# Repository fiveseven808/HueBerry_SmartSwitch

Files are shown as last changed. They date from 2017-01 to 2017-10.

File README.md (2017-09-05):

HueBerry: Smart Switch
=============
## IoT Smart Switch for the Philips Hue lighting system

Learn About the hueBerry! (https://youtu.be/YTvbsL82ZcM?t=1m3s "hueBerry is awesome!")

###### Video updated 8/13/2016 *(Outdated)*

## [Discord Channel here!](https://discord.gg/YxUusf8)

## Summary: Updated 2/7/2017
The hueBerry is a dedicated device based on a Raspberry Pi Zero to QUICKLY record and change between Whole house scene! Want to transition your entire home to "bed time" over 30 seconds? now you can! Want in instantaneous "emergency" mode? Now you can do that with ease! It also lets you to control the color temperature and Hue and saturation of individual groups through a quick and friendly interface! No fumbling with a phone or table or PC, just spin and click and spin!
##### Program is currently in open beta

### Features: Updated 9/05/2017

>  * [3D Printable Case!!! Courtsey of Daniel Back](https://www.thingiverse.com/thing:2180872)
>  * Clock! Dims (slightly) during night time (currently hard coded to 9pm)
>  * Control whole Groups and individual Lights!
>  * Control Color temperature and Hue and Saturation of lights OR groups! (for that precise control!)
>  * Assign quick actions to conveniently toggle your lights or set your favorite scene! 
>  * Flashlight mode lol
>  * Create then save whole house scenes with the push of a button! Replay and edit them just as easily!
>  * Adjust the transition time of the whole house scenes between Instant and 30 seconds!

### Technical Features: 

>  * Main menu times out to clock after 30 seconds (customization coming soon)
>  * Automatic Bridge detection and pairing initiation
>  * Scan and Connect to WiFi via WPS!
>  * Settings menu allowing Pi resets, shutdown, and Device and bridge info
>  * One command line install for super easy setup! (beta)
>  * OTA software upgrades!
>  * Unicode support! (beta)
>  * **Undocumented features**
>   * Non WPS WiFi APs added by a text file in the /boot partition
>   * Firmware upgrade possible via placing a special file in the /boot partition
>   * Console and Console Mirroring mode available (for remote debugging/control)

**Requirements:**

  * Optional: [3D Printable Case!!! Courtsey of Daniel Back](https://www.thingiverse.com/thing:2180872)
  * Raspberry Pi (a Zero W is suggested for size reasons)
  * Adafruit_SSD1306 library
  * pigpio library
  * SSD1306 compatible display (128x64 resolution)
  * Rotary encoder with momentary switch
  * Full BOM located [here](https://docs.google.com/spreadsheets/d/18q5wE9IcbJ1D823ktt4ZN7Fp1JHZutR4hCld2env4vI/edit?usp=sharing)

## Instructions as of 2/7/17

  * [Detailed instructions for developers available here!](https://github.com/fiveseven808/HueBerry_SmartSwitch/blob/dev/Dev_setup.md)

**Wishlist:**

  * Gotta clean up repo and get rid of my "training" files
  * More refined menu system programming
    * 2/7 update: Menu code is semi dynamic. Need to make every menu like this. Separate class?
  * Timeout to clock
    * 1/29/17 Needs to be configurable. Affect all menus? (not just main tree)
  * Disable clock via settings
  * Implement Guest mode
    * Guest mode will lock the hueBerry to one group or light allowing for ease of use, without "accidentally" affecting the rest of the house
  * PIR integration?
  * IR remote integration?
    * Push buttons on a universal remote to change scenes!
  * Lower power consumption
    * Move to ESP8266 architecture?
  * Battery state support and icon (low power indicator and graceful shutdown too)
    * Need to design
  * Bugs to squash:
    * Currently need to re-pair with bridge if bridge IP changes...
    * If API key doesn't work on boot, self troubleshoot and see if communication to bridge is bad or API key is bad?
	* Does not complain if bridge does not exist on boot
  * Multiple bridge support (looks like the N-UPnP discovery method supports it)
    * Whole house scenes spanning multiple bridges (for those lucky enough to have that problem lol)
  * This project will be shortly branched into a general toolkit and IoT menu platform for Raspberry Pi Zeros (although all Pis can make use of it)
    * The plan involves creating a custom distribution with all of the required files preloaded so that you can get a pi connected to WiFi with just a screen and a rotary encoder. No HDMI tv or USB widget fussing around necessary!
    * This is particularly useful if you find yourself in a situation where you don't have a computer to get started, but you own a smartphone and have an SSH or VNC app on it!

**License:**

[Creative Commons Attribution-NonCommercial 4.0 International ](https://creativecommons.org/licenses/by-nc/4.0/)  
This is an open source beta program supplied with no guarantee.

**Donations:**

If this project has been useful to you, I'd appreciate it if you would buy me a drink! :D



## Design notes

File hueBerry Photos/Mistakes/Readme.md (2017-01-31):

**Fried Display:**

Not all Chinese 4 pin I2c displays are the same. Their power pins may be switched compared to similar displays. 
The display in this picture underwent reverse voltage for a few seconds... Still works somewhat, but is very very dim. 

**Not like the others:**

Most cheap Wifi adapters (under $3 USD) worked fine with the raspberry pi in my exeperience. However, I ordered 2 
adapters from China that ended up being duds. They would work for a brief amount of time, and then quickly overheat and stop responding. 
In a desktop computer it would last a little longer (half day, then slowly went down to a few minutes, to seconds). Please thoroughly test all 
Wifi adapters before soldering or integrating it into a hueBerry as you may get a dud.

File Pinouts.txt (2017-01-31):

Raspberry pi -> Device
GPIO 16 - D+: Rotary Encoder
GPIO 20 - D-: Rotary Encoder
GND - D GND: Rotary Encoder
GND - Switch GND: Rotary Encoder

GND - GND: I2C SSD1306 128x64 display 
https://learn.adafruit.com/assets/17603
RST - Not connected (Chinese displays don't have this unfortunately)

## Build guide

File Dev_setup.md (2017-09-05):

hueBerry: Setup instructions for Developers
=============
### *"Bare-metal" install instructions for dev-kit*

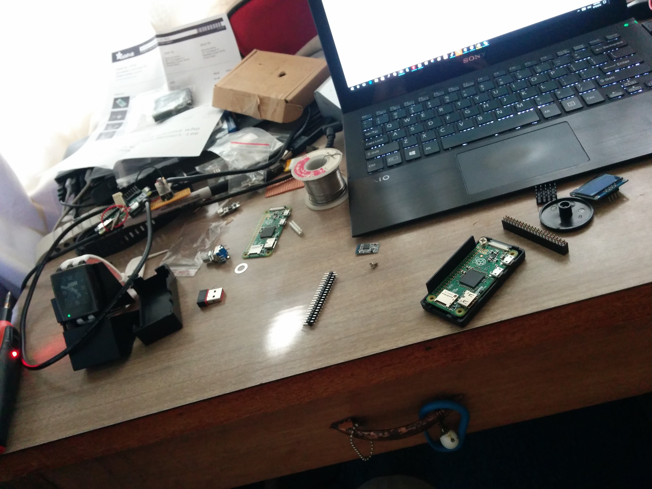
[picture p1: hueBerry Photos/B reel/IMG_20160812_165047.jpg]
hueBerry Mess!


## Getting Started: Updated 1/29/2017
Getting started with the hueBerry from a bare-metal pi is fairly simple. Here, I will attempt to guide you from start to finish!

**Requirements:**
  * Optional: [3D Printable Case!!! Courtsey of Daniel Back](https://www.thingiverse.com/thing:2180872)
  * Raspberry Pi (I used a Zero W)
  * Adafruit_SSD1306 library
  * pigpio library
  * SSD1306 compatible display (128x64 resolution)
  * Rotary encoder with momentary swtich
  * Full BOM located [here](https://docs.google.com/spreadsheets/d/18q5wE9IcbJ1D823ktt4ZN7Fp1JHZutR4hCld2env4vI/edit?usp=sharing)

**Do you meet the dev-kit minimum requirements?** Do you have a display, encoder, pi, and network connection? If so, you may continue! Otherwise, go back and get those components OR you can now run hueBerry in an emulated console session! 

## Bare-Metal Instructions:

* [Install the latest Raspbian distribution](https://www.raspberrypi.org/documentation/installation/installing-images/)
* Wire up the I2C display and rotary encoder (wiring diagrams coming soon)
* [Install the Adafruit_SSD1306 library](https://learn.adafruit.com/ssd1306-oled-displays-with-raspberry-pi-and-beaglebone-black/usage)
```bash
sudo apt-get update
sudo apt-get install build-essential python-dev python-pip
sudo pip install RPi.GPIO
sudo apt-get install python-imaging python-smbus
sudo apt-get install git
git clone https://github.com/adafruit/Adafruit_Python_SSD1306.git
cd Adafruit_Python_SSD1306
sudo python setup.py install
```
* [Install and run pigpiod](http://abyz.co.uk/rpi/pigpio/download.html)
```bash
rm master.zip
sudo rm -rf pigpio-master
wget https://github.com/joan2937/pigpio/archive/master.zip
unzip master.zip
cd pigpio-master
make -j4
sudo make install
sudo pigpiod
```
* You may want to add `sudo pigpiod` to your startup file (I used /etc/rc.local)
* Modify your `/boot/config.txt` file to enable I2c and speed up the bus
```
# Uncomment some or all of these to enable the optional hardware interfaces
dtparam=i2c_arm=on
dtparam=i2c_baudrate=1600000
#dtparam=i2s=on
dtparam=spi=off
```
* *Optional* Disable GUI (to speed up boot?) and lower GPU mem to 8mb
```
gpu_mem=8
start_x=0
```
* *Optional* Overclock your SD card bus to get faster boot speeds
```
dtparam=sd_overclock=100
```
* Clone hueBerry git dev branch then run the main program
```
cd ~
git clone -b dev https://github.com/fiveseven808/HueBerry_SmartSwitch.git
cd HueBerry_SmartSwitch

sudo python hueberry.py
```
* Follow instructions on the screen to pair your hueBerry and bridge
 1. On first run, it should ask you to pair with your Philips hue Bridge.
 1. Follow the onscreen instructions
* Enjoy!
 * *If the above instructions do not work, please contact the maintainer to correct this accordingly*

## OR!
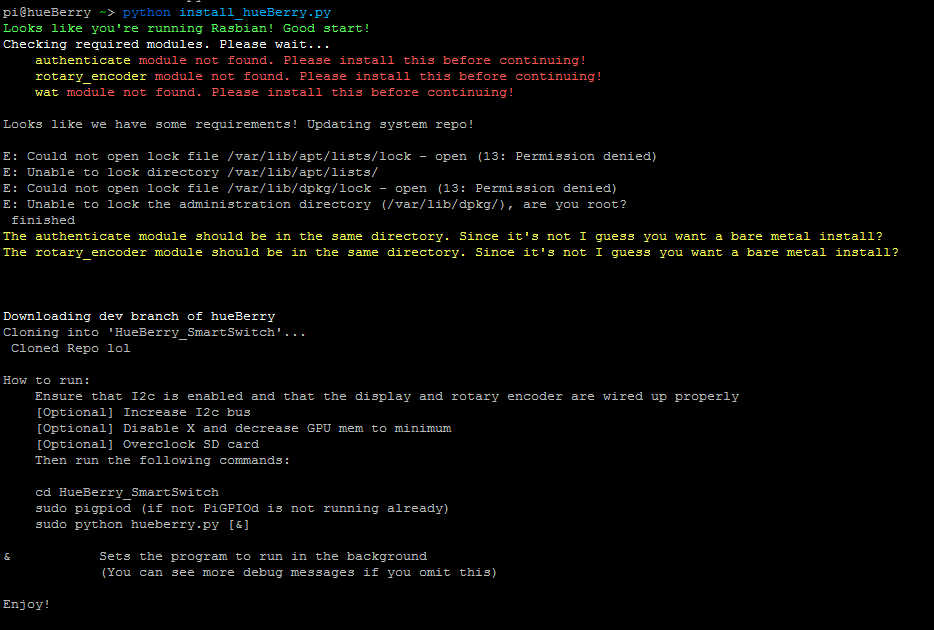
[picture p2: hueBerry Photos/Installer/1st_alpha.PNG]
Installer Beta

If you understand all of the instructions above then a new option is now available for you.
**[Just download the installer](https://github.com/fiveseven808/HueBerry_SmartSwitch/raw/dev/install_hueBerry.py)**
and run `sudo python install_hueBerry.py`. You should understand of the instructions above first is because
this installer is not fully tested and is in a beta state of usability.
But for all tests done so far it works, so I'll leave it here for now.

**License:**

[Creative Commons Attribution-NonCommercial 4.0 International ](https://creativecommons.org/licenses/by-nc/4.0/)  
This is an open source beta program supplied with no guarantee.

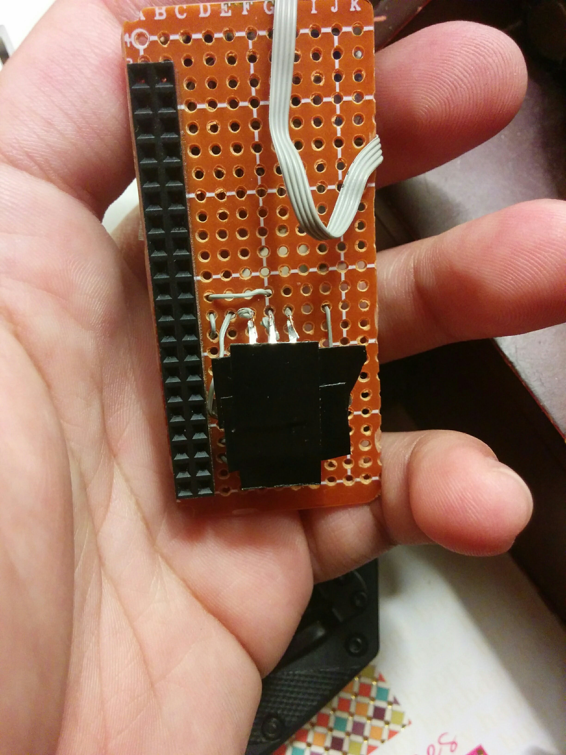
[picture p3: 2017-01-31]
hueBerry Photos/Construction/IMG_20160925_205121.jpg

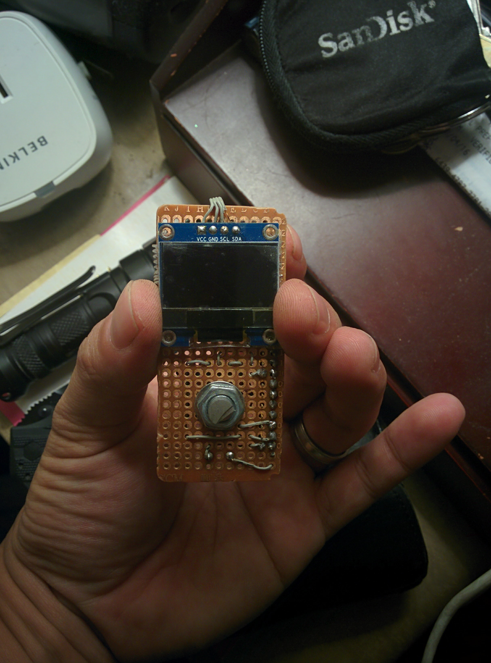
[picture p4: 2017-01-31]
hueBerry Photos/Construction/IMG_20160925_205027.jpg

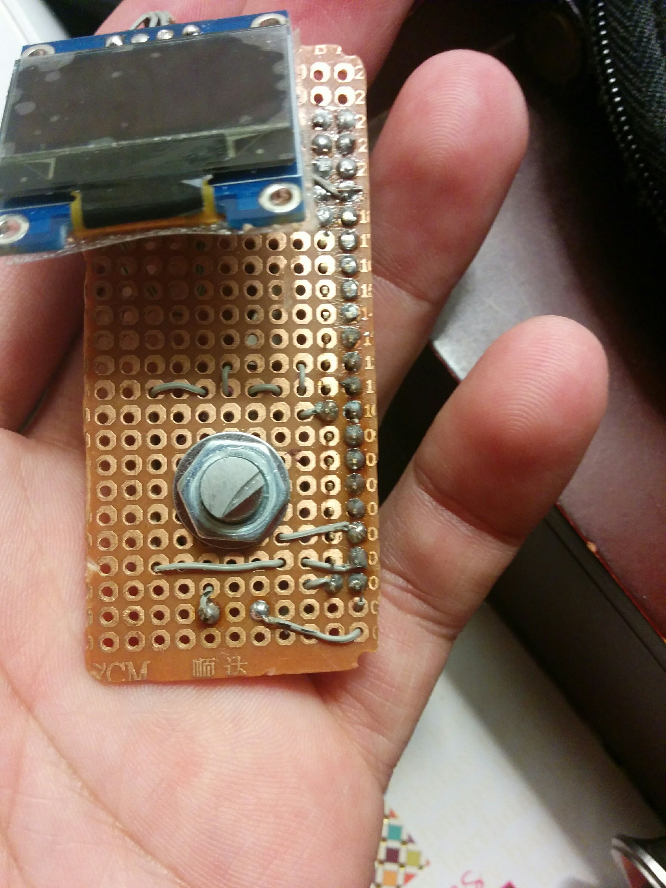
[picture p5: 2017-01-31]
hueBerry Photos/Construction/IMG_20160925_205115.jpg

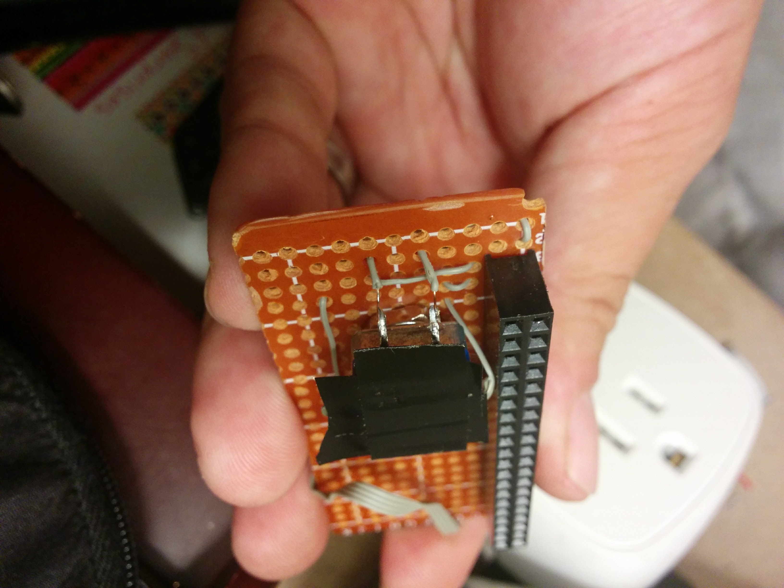
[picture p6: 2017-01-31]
hueBerry Photos/Construction/IMG_20160925_205156.jpg

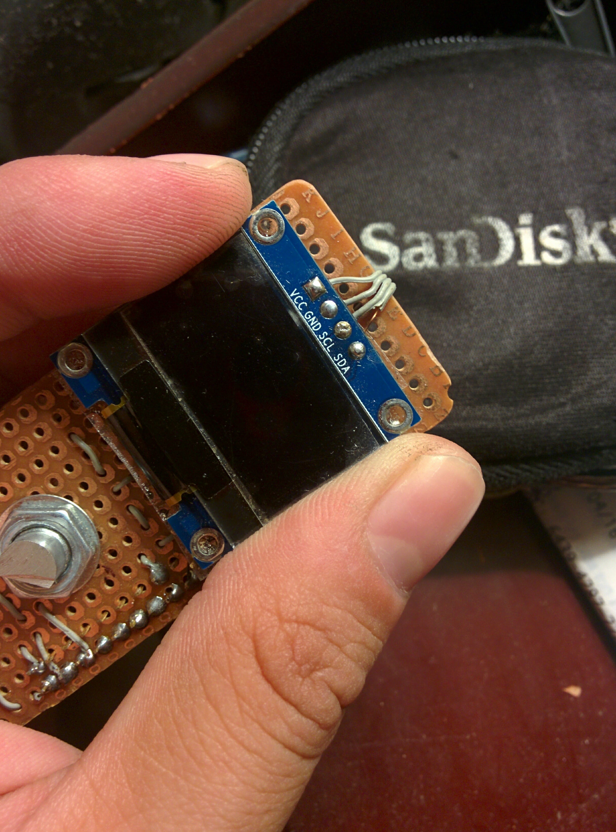
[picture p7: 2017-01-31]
hueBerry Photos/Construction/IMG_20160925_205051.jpg

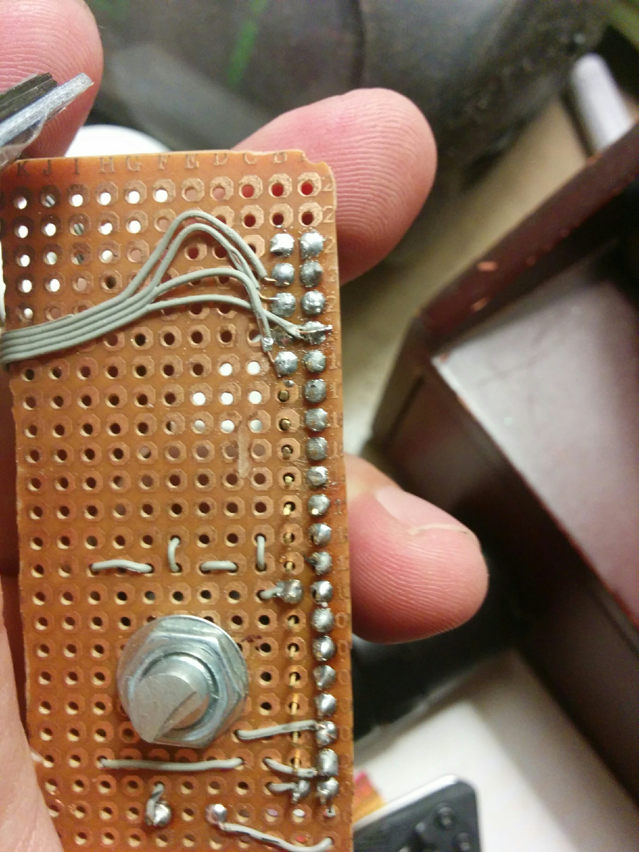
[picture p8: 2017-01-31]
hueBerry Photos/Construction/IMG_20160925_205110.jpg

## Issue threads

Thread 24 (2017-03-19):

Dead/deleted scene in quick actions are not obvious

fiveseven808, 2017-03-19:
Oh man... so lazy... gonna start writing issues in my own repo so i don't forget about bugs i need to squash LOL

If a scene that was assigned to quick actions was deleted, when run by the quick action, all appears normal, however the stdout prints that there is no file.

Remedy:
Somehow interpret the returncode of the process and display a message upon failure. I.e. "%scene% no longer exists"

fiveseven808, 2017-03-22:
fixed!

Closed 2017-03-22.

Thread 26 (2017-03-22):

Weird screen saver actions

fiveseven808, 2017-03-22:
If you push the button (without changing the display) during screensaver mode (screen blank) it runs a thing, but never updates the screen after that lol

Possible solution:
Make it reset the screensaver timer when a button is pushed?
Or make a button push something that wakes up the display? i.e. display 0 and screensaver and button push = timer reset?

fiveseven808, 2017-08-24:
i have no idea what this was for... it doesn't seem like its an isssue? or at least i dont remember what this was for lol

Closed 2017-08-24.

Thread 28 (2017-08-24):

CT not properly saved in Scene Creator

fiveseven808, 2017-08-24:
Not sure what the issue is (maybe a time/lag thing?) but CT does not seem to be saved on the CT only bulbs...

Gotta check on this since it's pretty annoying...

darakian, 2017-10-09:
What is CT?

fiveseven808, 2018-01-17:
Color Temperature. It's an attribute received in the JSON packet for a given light that supports it.

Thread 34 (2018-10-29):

Menu timeout not working

fiveseven808, 2018-10-29:
Haven't had time to address this...

Looks like the menu timeout isn't working properly in the current version

steps to reproduce:
change to a 1st level menu item that isn't clock
wait for timeout, no timeout happens... screen stays lit

however the internal menu counter seems to have reset to zero..

this will contribute to more burn in and is quite annoying

[additional] need to add the menu timeout to all levels of menu... should be a bit easier with the new menu code.

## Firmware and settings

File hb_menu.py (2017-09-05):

import hb_encoder
import hb_display
import time

class Menu_Creator(object):
    def __init__(self, menu_layout, debug = 0, mirror_mode = 0, rotate = 0, spi_display = 0):
        debug_argument = debug
        self.offset = 0 #carryover
        self.post_offset = 0 #carryover
        self.menu_layout = menu_layout
        self.exitvar = 0
        # Create Display Object
        # Maybe instead of create? get passed display object from hueberry? would make this less independent though... and confusing...
        if(mirror_mode == 1):
            self.hb_display = hb_display.display(console = 1,mirror = mirror_mode)
        else:
            self.hb_display = hb_display.display(console = debug_argument,mirror = mirror_mode, rotation = rotate, spi_display = spi_display)
        # Create Encoder Object
        if (debug_argument == 0):
            self.encoder = hb_encoder.RotaryClass()
        elif (debug_argument == 1):
            self.encoder = hb_encoder.RotaryClass(debug = 1)

    def run_simple_menu(self):
        """
        menu_layout = ("1st menu",lambda: printmenu("oshit! it works!"),
                    "2nd menu",lambda: printmenu("doing a second thing"),
                    "quit",lambda: sys.exit())
        """
        timeout = 0
        displaytemp = 0
        prev_secs = 0
        old_display = 0
        refresh = 1
        pushed = 0
        menu_timeout = 30
        depth_divisor = 2 # how many menu items per line. i.e. 1 title + 1 function = 2
        self.encoder.wait_for_button_release()
        while True:
            total_screens = len(self.menu_layout)
            total_plus_offset = total_screens + self.offset
            menudepth = (total_plus_offset + self.post_offset - depth_divisor)/depth_divisor
            # Cycle through different displays
            if(self.encoder.pos > menudepth):
                self.encoder.pos = menudepth
            elif(self.encoder.pos < 0):
                self.encoder.pos = 0
            display = self.encoder.pos*2 # because pos is a pre/bounded variable, and encoder.pos has been forced down.
            display_number = (display/2)+1
            #Display Selected Menu
            if (old_display != display or refresh == 1):
                if(display >= self.offset and display <= (total_plus_offset-1)):
                    self.hb_display.display_2lines(str(display_number) + ". " + str(self.menu_layout[display-self.offset]),"Run?",15)
                refresh = 0
                old_display = display
            time.sleep(0.005)
            secs = int(round(time.time()))
            timeout_secs = secs - prev_secs
            if(display != 0 and displaytemp != display):
                prev_secs = secs
                displaytemp = display
            elif(display != 0 and timeout_secs >= menu_timeout):
                self.encoder.pos = 0
                display_temp = 0
            elif(display == 0):
                displaytemp = display
            pos,pushed = self.encoder.get_state() # after loading everything, get state#
            if (pushed):
                if(display >= self.offset and display < total_plus_offset):
                    #print display
                    if self.menu_layout[display+(depth_divisor-1)] == "exit":
                        #print "exiting"
                        #time.sleep(2)
                        break
                    self.menu_layout[display+(depth_divisor-1)]()
                time.sleep(0.01)
                #prev_millis = int(round(time.time() * 1000))
                self.encoder.pos = 0
                refresh = 1
            #time.sleep(0.1)

    def run_2_line_menu(self):
        """
        menu_layout = ("Name 1", "Name 2", lambda: do_thing_1(),
                        "Name 3", "Name 4", lambda: do_thing_2(),
                        "Back to", "Main Menu", "exit")
        """
        timeout = 0
        displaytemp = 0
        prev_secs = 0
        old_display = 0
        refresh = 1
        pushed = 0
        menu_timeout = 30
        depth_divisor = 3 # how many menu items per line. i.e. 1 title + 1 function = 2
        return_status = 0
        self.encoder.wait_for_button_release()
        while True:
            total_screens = len(self.menu_layout)
            total_plus_offset = total_screens + self.offset
            menudepth = (total_plus_offset + self.post_offset - depth_divisor)/depth_divisor
            # Cycle through different displays
            if(self.encoder.pos > menudepth):
                self.encoder.pos = menudepth
            elif(self.encoder.pos < 0):
                self.encoder.pos = 0
            display = self.encoder.pos*3 # because pos is a pre/bounded variable, and encoder.pos has been forced down.
            display_number = (display/3)+1
            #Display Selected Menu
            if (old_display != display or refresh == 1):
                if(display >= self.offset and display <= (total_plus_offset-1)):
                    if callable(self.menu_layout[display-self.offset]) == False:
                        self.hb_display.display_2lines(str(display_number) + ". "+str(self.menu_layout[display-self.offset]),str(self.menu_layout[display-self.offset+1]),17)
                    else:
                        self.menu_layout[display-self.offset]()
                refresh = 0
                old_display = display
            #elif(display != 0):
            #    time.sleep(0.005)
            time.sleep(0.005)

            secs = int(round(time.time()))
            timeout_secs = secs - prev_secs
            if(display != 0 and displaytemp != display):
                prev_secs = secs
                displaytemp = display
            elif(display != 0 and timeout_secs >= menu_timeout):
                self.encoder.pos = 0
                display_temp = 0
            elif(display == 0):
                displaytemp = display
            #if(display != 0):
            #    print timeout_secs

            # Poll button press and trigger action based on current display
            #if(not GPIO.input(21)):
            #print self.exitvar
            pos,pushed = self.encoder.get_state() # after loading everything, get state#
            if (pushed):
                if(display >= self.offset and display < total_plus_offset):
                    #print display
                    if self.menu_layout[display+(depth_divisor-1)] == "exit":
                        # If a menu item has "exit" as the function/action thing, then exit
                        return 0
                    # Position [1] or [2] can be interpeted as type (all caps)
                    if self.menu_layout[1] == "BD_TYPE" or self.menu_layout[2] == "BD_TYPE":
                        # If BD_TYPE menu
                        if display != 0 :
                            return self.menu_layout[display+(depth_divisor-1)]()
                        if display == 0:
                            # Make sure to do nothing when the "Question" for BD_TYPE is selected
                            pass
                    else: # If normal type menu
                        # This is where the object that's selected actually runs...
                        return_status = self.menu_layout[display+(depth_divisor-1)]()
                    if return_status == "BREAK_MENU":
                        return
                time.sleep(0.01)
                refresh = 1
                #prev_millis = int(round(time.time() * 1000))
                self.encoder.pos = display/depth_divisor #resume where you came from
            #time.sleep(0.1)
        return

    def single_value_menu(self, main_title,value_title,
                                calc_func, rev_calc,
                                action_func,
                                start_pos,a_param,
                                min_val, max_val,
                                timeout, timeout_func):
        #Need to detmermine initial encoder position
        self.encoder.pos = int(start_pos)
        max_rot_val = max_val
        bri_pre = calc_func(self.encoder.pos)
        refresh = 1
        prev_mills = 0
        self.encoder.wait_for_button_release()
        pos = self.encoder.pos
        while True:
            if(self.encoder.pos > max_rot_val):
                self.encoder.pos = max_rot_val
            elif(self.encoder.pos < min_val):
                self.encoder.pos = min_val
            mills = int(round(time.time() * 1000))
            millsdiff = mills - prev_mills
            rot_bri = calc_func(self.encoder.pos)
            if(bri_pre != rot_bri or refresh ==  1 ):
                self.hb_display.display_2lines(main_title,value_title + str(int(rot_bri)) + "%",17)
                refresh = 0
            if rot_bri <= min_val and rot_bri != bri_pre:
                print"turning off since below min value"
                #hue_groups(lnum = group,lon = "false",lbri = rot_bri,lsat = "-1",lx = "-1",ly = "-1",ltt = "5", lct = "-1")
                #huecmd = threading.Thread(target = hue_groups, kwargs={'lnum':group,'lon':"false",'lbri':int(rot_bri),'lsat':"-1",'lx':"-1",'ly':"-1",'ltt':"5",'lct':"-1"})
                #huecmd.start()
                bri_pre = rot_bri
            elif(rot_bri != bri_pre and millsdiff > 200):
                print"millsdiff > 200"
                print"running actionfunc with rot_bri calcuated result"
                action_func(pos)
                #hue_groups(lnum = group,lon = "true",lbri = rot_bri,lsat = "-1",lx = "-1",ly = "-1",ltt = "5", lct = "-1")
                #huecmd = threading.Thread(target = hue_groups, kwargs={'lnum':group,'lon':"true",'lbri':int(rot_bri),'lsat':"-1",'lx':"-1",'ly':"-1",'ltt':"5",'lct':"-1"})
                #huecmd.start()
                bri_pre = rot_bri
                prev_mills = mills
            millsdiff = mills - prev_mills
            if(millsdiff > timeout):
                #If 5.0 seconds have passed and nothing has happened, go and refresh the display and reset the miliseconds
                #rot_bri,wholejson = get_huejson_value("g",group,"bri")
                self.hb_display.display_2lines(main_title,value_title + str(int(rot_bri)) + "%",17)
                timeout_func(pos)
                print "the rot bri after 5 sec is: "+str(rot_bri)
                prev_mills = mills
            pos,pushed = self.encoder.get_state()
            if(pushed):
                return #exit function goes here
            time.sleep(0.01)
            refresh = 1


def printmenu(text):
    print(text)
    time.sleep(1)

# For testing
if __name__ == "__main__":
    import hb_menu
    import sys
    tm_menu = ("1st menu",lambda: printmenu("oshit! it works!"),
                "2nd menu",lambda: printmenu("doing a second thing"),
                "3rd menu",lambda: printmenu("doing a third thing"),
                "quit",lambda: sys.exit())
    testmenu = hb_menu.Menu_Creator(debug = 1,menu_layout = tm_menu)
    testmenu.run_simple_menu()

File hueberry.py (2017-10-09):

#!/usr/bin/env python
__version__ = "v051-0905.57.a"
"""
2017-09-05 //57
* I really want to update the master branch... So this is some simple modifications to undo the dev features
- Scene upgrader removed and placeholder in place right now
+ Added WPBack's 3d printable model of the hueBerry case!!!
+ Want to push to master!

2017-07-24 //57
* Have not touched this code in 3 months it seems... I don't remember how this
    works lol. Will attempt to add scene updater tool...
* Scene updater tool will work as follows:
    * User replaces lights in system.
    * Navigate to and run Scene Updater
    * Selects how many lights to replace (and option to cancel)
    * Select 1st light to replace (and option to go back or cancel)
    * Select 1st light to replace with (and option to go back or cancel)
    * Select n light to replace (and option to go back or cancel)
    * Select n light to replace with (and option to go back or cancel)
    * Dict? List? Array? Will be created like {(lights:1, 15),(lights:2, 16),(lights:10, 17)}
    * Menu title: Lights to be replaced
        * Mappings will be displayed in a scrollable style (and option to cancel)
        * Future features:
            * Detect if a mapping error has occured (multiple lights mapped to same light, etc)
            * Click to edit individual Mappings
        * Submit button
        * Binary decision menu to confirm that it will affect all scenes
    * Will parse/grep/replace the "*lights/1*" string with the "*lights/15*"
        string in all files in the scenes directory

2017-04-30 //57
+ Fixed a bug preventing scenes from being created

2017-04-07 //57
* Mega Alpha version
* Forgot to add release notes LOL
+ Intelligent Display handling (kind of)
+ Check I2C display, if not, then SPI, if not then morse code IP address via onboard LED!
+ Rotate display is a thing now (not tested well)
+ Dynamic menu struture implemented
+ Enforced running as root
+ Created a non-root mode
+ Added a demo mode (super alpha)


--------
Things to do
Short term goals:
*
Long term goals:
* Handle adding Wifi without screen? (try except displaying on a screen?)
* If no screen is detected, signal via the onboard led that wifi adding is complete?
* Dynamic (or seperate) Menu for Util mode? (Clock, Util Settings menu, chck for programs not scenes)



--------------------
http://www.diveintopython.net/scripts_and_streams/command_line_arguments.html
this is probably a good reference on how to program this in the future
--------------------
bug:
--------------------
philips hue bug
need to repair when no bridge found

search and test auth?
ping on startup?

check for response?
nothing found?
"""

def print_usage():
    usage = """
    How to run:
        sudo python hueberry.py [-d] [-m] [-s] [-nb] [-wsl] [-util] [-r180] [-spi] [-h,--help]

    -d              Sets the program to output and take input from the console

    -m              Turns on mirror mode. Outputs to the
                    display as well as the terminal.

    -s,--simulate   Set the updater to simulate mode ( no changes made )

    -nb             No Bridge mode. Run this if debugging with no bridge

    -wsl            Disables weird logging (quick fix for Windows Subsystem for Linux)

    -util           Turns on HB-Utility mode. No hue related options avaliable.
                    Faster boot time too

    -r180           Flip the display 180 degrees

    -spi            Run hueBerry with a SPI driven SSD1306 display vs I2C

    -nr, --noroot   Allows hueBerry to run as a normal user with REDUCED functionality
                    The following features WILL NOT WORK and may crash the program:
                    OTA Updater, Add wifi via txt file, Update via file on sd card,
                    View IP (possibly), Connect to Wifi, Exit to terminal

    -h,--help       Displays this help text

    ex: python hueberry.py -d -nb -wsl -nr
    This will allow hueberry to run in WSL without the hue system or root
    """
    print(usage)

import os, logging
#set working directory to script directory
os.chdir(os.path.dirname(os.path.abspath(__file__)))

import sys
#Defaults
debug_argument = 0
mirror_mode = 0
bridge_present = 1
wsl_env = 0
simulation_arg = 0
rotate = 0
curses_test = 0
util_mode = 0
spi_display = 0
rootless = 0
for arg in sys.argv:
    if arg == '-d':
        debug_argument = 1
    if arg == '-m':
        mirror_mode = 1
    if arg == "-nb":
        bridge_present = 0
    if arg == '-wsl':
        wsl_env = 1
    if arg == '-util':
        wsl_env = 1
        bridge_present = 0
        util_mode = 1
    if arg == '-r180':
        rotate = 180
    if arg == '-curses':
        curses_test = 1
    if arg in ("-s","--simulate"):
        simulation_arg = 1
    if arg in ("-spi"):
        spi_display = 1
    if arg in ("-nr","--noroot"):
        rootless = 1
    if arg in ("-h","--help"):
        print_usage()
        sys.exit()

if debug_argument != 1:
    os.popen("python splashscreen.py &")

import threading
import time

import authenticate

import json
import colorsys
import math
import pprint
import hb_display
import hb_encoder
import hb_hue
import hb_settings
import hb_menu
import curses

print "Finished Importing all modules! hopefully this will work!"

# For when I want to measure the time of all of the modules loading
# Using the dot graph method Described here:
# http://stackoverflow.com/questions/767881/time-taken-by-an-import-in-python
#sys.exit()
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

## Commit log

2016-08-12 v008 update
    v008 update
    uses the functions built in 007 and now automatically
    retrieves group and light names from the hub
    now when using the group or
    light modifier, you'll know exactly what you're controlling
    and in case
    you have dead light spots (i.e. removed from system) then it'll skip
    over that as well.
    deleted a couple of functions that aren't being
    used anymore.
    also added to the brightness change function to get the
    state of the light before hand and update it
    changed representation
    from 0-250 to 0-100%
    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
    [v005.py, v006.py, v007.py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]
2016-08-14 authenticate module
    This module is set up so you don't need to hardcode any info. you can create a "auth" option on the device that will run through the necessary steps to auth. see authtest.py for a crude example
2016-08-15 fixed issue
    didn't test the lights as i should've... wasn't working. fixed the issue
    with a space LOL. the new url string wasn't seperated properly LOL
    [v011.py]
2016-08-16 v012 update. big ass update! added a new menu with 2 items!
    v012 update
    This is going to be my workspace for today.
    Running splash screen so that you dont have to wait as long before
    something shows up on the screen.
    edit: it does fucking nothing
    added a settings screen
    added device info screen (ip's and shit)
    put the repair device there, delets the auth.json upon running. no
    verification if you want to continue though LOL
    reworked the main menu numbers, so it's a bit easier to shuffle things
    around.
    reworked the order of the menu.
    most used functions in the front and back. i..e turn off all lights
    slowly is on the front, and group control is on the back. group >
    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
    [authenticate.py, splashscreen.py, v012.py]
2016-08-19 v014 update
    added a wifi menu :D now you can start up with absolutely nothing and
    connect to wifi via WPS!!!!! get your raspberry pi started with just a
    hueBerry hat! so happy!!!
    also added a display timeout for the main menu. Unfortunately it only
    works for the main menu... but it's still pretty cool :D
2016-08-20 v15 update!!! performance increase!!!
    omg!!!! solved the performance issue! device is MUCH more responsive
    when turning the dial. no longer wastes massive amounts of cpu trying to
    redraw the screen when there's nothing to redraw!!!! applied it to all
    menus. LOVE IT!
    [v015.py]
2016-08-20 minor bug fix
    the "timeout to clock" part was freaking out and not letting you advane
    through the menu sometimes. think i fixed it...
    [v015.py]
2016-08-26 Big ass changes
    faster display rendering. faster brightness setting. change CT mode
    added. functions consolidated. lower power and cpu usage. basically a
    new version already lol
2016-09-08 v021 update
    updated brightness and CT controls with multithreading. display is a
    million times more reponsive when adjusting bri and CT. just gotta add
    it to hue and saturation. fuck yeah!
2016-09-09 v022 update!
    hue and sat multi threading! SO easy to use now! no more guessing
    values!
2016-12-27 v024 update!
    v024
    20161226 1917
    looks like the automatic wifi addition works fine!!!
    - now reboots after adding file.
    made the auto wifi addition script into a function
    v024
    20161226 0138
    going to try to add automatic wifi addition via file in /boot etc.
    /boot/add_wifi.txt
    looks like it goes through the motions and adds it... just gotta test it
    - need to ask yes or no
    - need to ask yes or no on delete
    added reboot to settings menu
    fixed device info resource hog. now consumes next to nothing when
    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
    [v023.py, v024.py, v025.py]
2017-01-08 v028 update
    v028
    20170108
    removing group 5 from turn on all lights
    added debug function and trying to figure out calvins problem
    added error handling for hue lights and hue groups function in case
    calvins thing freaks out
    added proper failed return values so it fails gracefully
    v027
    20170106 1025
    changing display dimish time to 9pm on both date and time
    v026
    20170103 1117
    adding error handlig to the light functions so they dont crash when
    viewing a group that has no bulbs or a nonexistant group
    [pythondaemon.py, v026.py, v027.py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]
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2017-01-30 final dev_setup update
    pythondaemon.py updated to be more generic
    dev_setup should be good for now, until people find issues with it
    [pythondaemon.py]
2017-01-31 20170130 2028 Release Candidate
    No obvious runtime errors. Merging into master after commit (or going to
    try to)
    [hueberry.py]
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2017-02-01 v034 push
    error handling and retrying. confirmed working on calvins hueberry.
    [hueberry.py]
2017-02-01 10s to 0.4s transition time
    updated public to 0.4 transition time for created scenes. so it doesn't
    look like its doing nothing
    [hueberry.py]
2017-02-03 v035 2243
    looks like i fixed the CT issue. i had quit the CT function too early in
    my last error handling. it shoul dbe a lot better now... i think there's
    an else statement somewhere in there that doesn't need to be... i put
    some markers just in case it gets called....
    [hueberry.py]
2017-02-03 Added ct_to_hue_sat-method
    Added the method ct_to_hue_sat that converts color-temperatures into hue
    and saturation-values scaled for the Hue-system.
    For use with the old LED-strip and other lights that doesn't support
    CT-settings.
    Not implemeted anywhere yet though, and not tested enough
    [hueberry.py]
2017-02-03 v036 2017-02-03 0958 //57
    Tweaked the debugmsg string input for WPBack's new method.
    Added easy to turn off global variable for debugmsg: debug_state
    Implemented WPBack's new function to enable CT for "Color Lights" as
    well as calculate and send back hue/sat to a group after 0.5s to look
    for color wobble
    Cleaned up ct_control a little bit.
    UNTESTED (but runs without any obvious errors)
    [hueberry.py]
2017-02-04 adding debug argument
    debug argument doesn't work. help does. my guess is that everything will
    run fine so long as you dont specify debug... working on module.
    [hueberry.py]
2017-02-04 #thereifixedit
    it ran, but didn't work... well kind of ran... well, not at all... turns
    out CT -> hue results in red... putting it on hold for now. on the
    bright side, individual CT control of "color lights" is still enabled.
    [hueberry.py]
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2017-02-05 minor detail
    can't figure out the whole pipe output from os.popen to console... so
    i'm blocking this.. unfortunately i still get the error "(23) Failed
    writing body"
    anyone have any ideas?
    [hueberry.py]
2017-02-11 v040 update
    v040
    2017-02-10 1610 //57
    Extra bigass update. Just like Windows 10, skipping a few versions to
    get to v040. I'm pretty sure I made a whole bunch of little updates and
    just didn't push them to git. Will do my best to document all of them.
    * Changing the working directory structure for hueBerry
    * Now using /boot/hueBerry/ for upgrade and wifi settings
    * Now using /boot/hueBerry/scenes/ for scene files!
    * Psuedo Global variable used (passed around a lot lol)
    * "Should" automatically create the directories if they don't exist
    already
    * Changed get_house_scene_by_light's parameter to selected_filendirect
    because I'm now passing it a full path name of a file
    * Can be optimizied a litt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
    [hueberry.py]
2017-02-11 v040 bug fixes
    bug fixes, scenes now refresh after exiting from settings menu
    i think this is stable, just need to confirm by deploying
    [hueberry.py]
2017-02-11 test
    bleh not much changed... trying to figure out how to nicely iterate
    through something that doesn't matter too much
    [hueberry.py]
2017-02-11 fixed errors
    pigpio installer no longer stops when it can't remove the old stuff (lol
    idk why that's even there)
    also edited the adafruit installer command. for some reason i put the
    python command in the wrong place. i believe it'll run fine now!
    [install_hueBerry.py]
2017-02-12 bug fixes
    removing some debug statements
    [hueberry.py]
2017-02-12 bug fixes
    wasn't working right. hopefully working now
    [hueberry.py]
2017-02-12 update bug fixes
    meh... idk what i'm doing anymore lol
    [hueberry.py]
2017-02-12 bug fixes
    chown shit.... learning this...
    [hueberry.py]
2017-02-13 bug fixes
    turning all lights on full has negative transition time
    [hueberry.py]
2017-02-13 oops missed one lol
    [hueberry.py]
2017-02-14 still more bug fixes
    lol github is my test/file server
    [hueberry.py]
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2017-02-15 bug fixes
    removed auto download and replace in the begnning
    [hueberry.py]
2017-02-15 bug fixes
    settings menu should now iterate through all of the optinons. display
    was referencing a bunk value
    [hueberry.py]
2017-02-15 bug fix. weird dev info screen behavior
    only when doing console though
    [hueberry.py]
2017-02-15 fixing all of the menu bugs
    bleh
    [hueberry.py]
2017-02-15 more bug fixes
    i giive up. contained globals it is lol
    [hueberry.py]
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2017-02-16 bug fix
    pushed still used gpio
    [hueberry.py]
2017-02-20 bug fixes
    implemented the new value getter code in all of the functions that
    needed it... i think
    [hueberry.py]
2017-02-20 bug fixes
    mirror mode will work without debug mode now. also, put all curl
    commands to silent... this is in prep to switch to the requests module
    instead of cURL...
    [hueberry.py]
2017-02-21 2017-02-20 //57
    finally put to use that holding_button function i made a while back
    went and optimized the light_control function a little bit... light
    control can really be cleaned up...
    but first g_control and l_control need to be reworked into one function.
    [hueberry.py]
2017-02-21 bug fixes
    stopped the lights from immediately changing when switching through the
    different modes
    [hueberry.py]
2017-02-21 bug fixes
    cleaned up commeneted out code, and made the encoder object instantiate
    immediately after the display object to fix the initial pairing crash
    bug.
    [hueberry.py]
2017-02-21 credential fixes
    fixed a bug where a fresh install wont control lights, missing the
    api_url thing. just merged it all into one if statement.
    [hueberry.py]
2017-02-22 upgrade_hb file!
    extraneous spaces removed from hueberry.py
    hb_display has a new function added (ajnd test code hopefully)
    upgrade_hb is untested and probbaly doesn't work but i wanna test
    hb_display now
    [hb_display.py, hueberry.py, upgrade_hb.py]
2017-02-22 bug fix
    tried to add max text limit
    [hb_display.py]
2017-02-22 update bug fixes
    i got a good feeling
    [hueberry.py, upgrade_hb.py]
2017-02-22 enable unicode support
    can write scenes with unicode now. not sure about display yet... we'l
    see if it crashes
    [hb_display.py, hueberry.py]
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2017-02-22 v044 update (#13)
    * first object test ever!!!!
    excited!
    * oops missed one lol
    * console test 1
    * cleaning things up
    * console mode temporary addition
    * temporary enable until i figure out how to reroute console input
    * still more bug fixes
    * trying to be all fancy
    adding a clear statenent to the function
    * added a mirror mode
    * prettifiy clock
    * bugfix
    also trying to add a control class
    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
    [hb_display.py, hb_encoder.py, hueberry.py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]
2017-02-22 bugfix
    this is my file server lol
    [upgrade_hb.py]
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2017-02-22 bugfix
    can run upgrade_hb.py seperately and it should work and run the latest
    everything now
    [hueberry.py, upgrade_hb.py]
2017-02-23 bugfix for 0.4s transition time
    [hueberry.py, upgrade_hb.py]
2017-02-23 bugfix and new function
    test function for clock. may be able to do something now
    [hb_display.py, hueberry.py]
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2017-02-23 1754
    1754
    Button routines optimized for console
    bug fixes
    [hueberry.py, upgrade_hb.py]
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2017-02-24 2012-02-24 //57
    + hueberry now works on WSL!
    - Installer doesn't work for WSL yet
    + Added a couple of switches for WSL and no bridge testing
    [hb_display.py, hb_encoder.py, hueberry.py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]
2017-02-25 1403 //57
    + Fixed the updater function and display libraries to work in console
    mode better (doesn't affect prod
    [hb_display.py, hueberry.py, upgrade_hb.py]
2017-02-25 bug fixes
    fixed not running on pi issue....
    removed huepi since it's not used... better to just build a new hue api
    class file since i know what im doing now
    added console_colors as a class to just dump in files that i want to add
    color too lol.
    cleaned up the imported modules for install_hueberry
    added console_colors to upgrade requirements? since some hb_encoder now
    needs it
    visual improvements for hbencoder console mode. also added a quit
    command
    [hb_encoder.py, install_hueBerry.py, upgrade_hb.py]
2017-02-26 fixed wsl bridge pairing
    could not pair with hue bridge in wsl. it called a variable before
    being established. not anymore
    [hueberry.py]
2017-02-26 fixed the flashlight thing
    flashlight now works again
    [hb_encoder.py, hueberry.py, upgrade_hb.py]
2017-03-01 readme update, fix and new encoder api implementation
    sync before home
    [hb_encoder.py]
2017-03-01 1150
    shit... bugfix lol. crashed my devhb after an update hahaha. typos in
    the new addition.
    [hb_encoder.py]
2017-03-01 spot check bug fix
    [hb_encoder.py]
2017-03-02 New code styling promise + hb_hue updates
    https://google.github.io/styleguide/pyguide.html
    gonna try and rework as much of the code as i can to get this to this
    new nice style
    [authenticate.py, hb_encoder.py, hb_hue.py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]
2017-03-02 error handler implemented!
    erorr handler now works. and you can run functions via a process monitor
    that will use the error handler to output information.
    [hb_hue.py]
2017-03-03 bug fixes then gonna merge this shit back...
    [hb_hue.py, hueberry.py, upgrade_hb.py]
2017-03-03 notes update
    fixed WSL menu glitch for WPBack's update
    updated upgrade file
    [hueberry.py, upgrade_hb.py]
2017-03-03 small updates + unfinished hb_menu module
    small bug fixes for devinfo_screen lol and HUGE news!!!! menus can be
    created dynamically!!!!! module is unfinished, but it works, and i want
    to commit it before i break it LOL
    [hb_menu.py, hueberry.py]
2017-03-03 corrupted?
    something weird happened with the commit. this is the correct version
    though...
    [hb_menu.py]
2017-03-03 1244 //57
    + Added hb_menu module (not used yet)
    - Partially impelemented, doesn't quite work though so not activated
    * Changed Turn on Nights dim functionality
    - Should in theory turn all lights that are currently on to 1 brightness
    over 10 seconds
    [hb_menu.py, hueberry.py, upgrade_hb.py]
2017-03-04 1405 //57
    + Implemented hb_menu module for settings. Things look okay for now
    + Fixed handling of lots of things in hb_menu.
    * Keep an eye out for bugs in the settings menu for this commit.
    + Secret menu test works too!
    [hb_menu.py, hb_settings.py, hueberry.py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]
2017-03-04 bugfix
    debug argument wasn't passed correctly. would cause a background running
    hueberry to crash
    [hueberry.py]
2017-03-04 error handling for get_huejson_value
    now fails gracefully... hopefully
    [hueberry.py, upgrade_hb.py]
2017-03-06 binary decision ported
    hb_menu upgrades
    now handles binary decision type function lol
    can take lambdas for the menu options actually (yay expandability!)
    don't need a specific "exit" item to exit, can now set BD_TYPE and exit
    on any click (except the 1st)
    BinaryDecision now runs off of the new menu code. old one is still there
    in case i can't fix something
    [hb_menu.py, hueberry.py]
2017-03-06 Added circuit diagrams
    Created using Fritzing. Could not use the Pi Zero since it didn't want
    to export. Also I couldn't find any encoder with a switch integrated, so
    it isn't perfect. You can decide if you want to add it to the readme or
    wiki, or not use it at all until it is fixed
    [CircuitDiagram.fzz]
2017-03-06 bugfixes and moved set_action
    set_action now on new menu system.
    old functions/ unused code cleaned up now lol
    [hb_menu.py, hueberry.py]
2017-03-06 bug fix
    fixed the wait_for_button_release function, and made it only applicable
    to non-console interface
    made the button wait in the hb_menu thing so if you're holding down the
    button, it doesn't continiously register presses.
    [hb_encoder.py]
2017-03-06 bugfix
    i am an idiot :laughing:
    this should fix it
    [hb_menu.py]
2017-03-07 improved performance
    forgot to check for a sleep in the menu code properly. this may or may
    not fix things...
    added placeholders for future feature additions (hopefully)
    [hb_menu.py, hueberry.py]
2017-03-07 bugfix
    hopefully improvews responsiveness of the program without having to use
    interrrupts
    [hb_menu.py]
2017-03-07 bugfixes
    bugfixes, improving usability on physical hueberry
    added some documentaiton to the menu functions. started working on new
    menu function,
    easier to set transition time on hueberry (if you hold the button down)
    preferences menu now correctly exits to settings menu
    [hb_menu.py, hueberry.py]
2017-03-07 fixed the file-wifi-adding thing
    bug would append ^M everytime it saw a /r/n which apparently is a
    microsoft thing.
    wrote in a handler for that lol
    also, should work for UTF SSIDs and PSKs if that's possible lol
    also, added the special_files thing so at least it's documented in some
    fashion
    [hueberry.py]
2017-03-08 rotate fixed
    using globals though... shit
    [hb_display.py, hb_menu.py, hueberry.py]
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2017-03-11 bugfix
    ran the installer from master... seems like the adafruit library doesn't
    always install properly
    this seems fairly stable. gonna merge it with the master
    [authenticate.py, hueberry.py]
2017-03-11 "v046-0311.57.a"
    + Added decision instead of forcing adding of credentials if hue bridge
    is found
    + Attempting to fix installer.... although hard to test...
    [hueberry.py, install_hueBerry.py]
2017-03-12 commiting changes before i can't anymore
    omg everything is broken
    [hueberry.py, install_hueBerry.py]
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2017-03-13 broke, but i still need to sync...
    authentication no longer works after util mode added...
    [hueberry.py]
2017-03-13 tentative fix
    bridge pairing should be fixed... i think...
    also added a confirmation before cred deletion upon re-pairing
    i've lost too many credential files accidentally that way LOL
    [hueberry.py]
2017-03-14 v047-0313.57.a
    2017-03-13 //57
    + Added a changelog viewer now! :D It's bare bones and kinda junk, but
    better than nothing!
    + Fixed authentication issues... Can do initial pair at least.
    + Cleaned up some bits of code
    [hb_display.py, hueberry.py, upgrade_hb.py]
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2017-03-16 goddamnit, a typo broke the updater...
    hopefully this fixes things
    [upgrade_hb.py]
2017-03-16 v047-0315.57.a
    bug fix, added a wait for the scene explorer. i got spolied with the new
    menu code lol
    [hueberry.py, upgrade_hb.py]
2017-03-16 bug fix...
    i think i figured out what is happening... version before v047 can't use
    the new upgrade format...
    [upgrade_hb.py]
2017-03-18 menu organizational change
    + Reworked the settings menu so it's not so long and ridiculous
    [hueberry.py, upgrade_hb.py]
2017-03-19 v048-0319.57.a
    2017-03-19 //57
    + Added the ability to select a scene for Quick actions
    * Needs a lot of work on the code side though to get readable
    * Fixed a bug with binarydecision (would crash if you clicked on the
    question)
    [hb_menu.py, hb_settings.py, hueberry.py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]
2017-03-20 2017-03-19 //57
    * Fixed a bug where wifi APs wouldn't show up sometimes. Also reordered
    them.
    [hueberry.py, upgrade_hb.py]
2017-03-21 slowly but steadily
    small rework
    [hb_settings.py]
2017-03-22 LOL woww...
    first time in ever my error messages finally work :laughing: i'm glad
    this issue is kind of solved though :)
    [upgrade_hb.py]
2017-03-24 attempting minor bug fix
    added debug mode to the wifi scanner
    attempting to fix initial screensaver timeout, and timoutafter button
    pushed
    [hueberry.py]
2017-03-24 2017-03-24:
    + Fixed screensaver timeout on action
    [hueberry.py, upgrade_hb.py]
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2017-03-26 upgrade going up
    modified things so they're more geneirc. no longer need strange paths
    for everything just run and it works :)
    [hueberry.py, splashscreen.py, upgrade_hb.py]
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2017-03-26 bugfix
    it wasn't properly deleting the old files
    [upgrade_hb.py]
2017-03-26 more bug fix
    gotta make sure that r2hb is runable lol
    [upgrade_hb.py]
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2017-04-07 LOL
    so...... i think now, if the display driver doesn't detect any displays
    (if not told to run in console mode) it'll start spitting out the IP
    address of the pi via the power/ACT LED in morse code LOL
    [hb_display.py]
2017-04-07 bug fix
    added \n so when interpreting the linefeed at the end of the string, the
    program doens't freak out and crash LOL
    [hb_morse.py]
2017-04-07 bug fix
    ip2morse confirmed working for i2c. i.e. if spi is disabled (becuase you
    run an i2c display) it'll work if ther is no i2c display connected.
    if spi is enabled, the process fails though.
    [hb_display.py]
2017-04-07 order was screwed up
    oops lol. okay, now it's fixed.
    [hb_display.py]
2017-04-07 updates and features!
    fixed the display api's description
    added the ability to mirror the morse code on the console and the
    hueberry so it's easier to try to learn how to read the lights
    [hb_display.py, hb_morse.py]
2017-04-07 bugfix
    mirror mode fixed lol
    [hb_morse.py]
2017-04-07 added the no root option
    you can now launch hueberry without running as root (as a test or
    whatever)! you will just lose a lot of functionality or crash the
    program when trying LOL
    [hueberry.py]
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2017-04-08 morse code fix
    console output is now broken up nicely
    [hb_morse.py]
2017-04-08 fix? hopefully this works
    [hueberry.py]
2017-04-08 fixed a few things
    fixed high brightness value when light is off bug (i think)
    everything else looks fine to me though...
    [hueberry.py]
2017-04-08 blehhh
    shittly fixed error handling for demo mode... ugh... its so ugly... but
    i need to go to sleep
    [hueberry.py]
2017-04-10 i think i fixed demo mode
    works fine in the console. it was missing the demo-files so i just added
    a check so that it runs off of the groups and lights file if it cant
    find the demo file.
    [hueberry.py]
2017-04-11 bug fix
    oops.... special modes would crash. i fixed it.
    [hueberry.py]
2017-04-30 v050-0430.57.a
    2017-04-30 //57
    + Fixed a bug preventing scenes from being created
    [hueberry.py, upgrade_hb.py]
2017-08-24 comments and fixes
    cleaned up the function a bit, uploading before going to bed
    [hb_sceneUpdater.py]
2017-08-28 Revert "quicksave"
    This reverts commit b8be3758cb1cc83a0af0ed5dd3b9bb3b9f4956db.
    [hueberry.py, upgrade_hb.py]
2017-08-28 Revert "Revert "quicksave""
    This reverts commit 120567ee0162669b3b5ecacc069630a7d1660210.
    [hueberry.py, upgrade_hb.py]
2017-09-05 readme updates
    Finally got around to adding the beautiful 3D printable case created by
    @WPBack
    Updated discord channel link so that it actually works LOL
    Swaped out features and technical features so that it will present
    itself in a hopefully more interesting way to people who dont care about
    the technical features.
